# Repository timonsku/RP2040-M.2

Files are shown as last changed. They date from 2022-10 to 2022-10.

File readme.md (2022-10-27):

## RP2040 M.2 USB Card

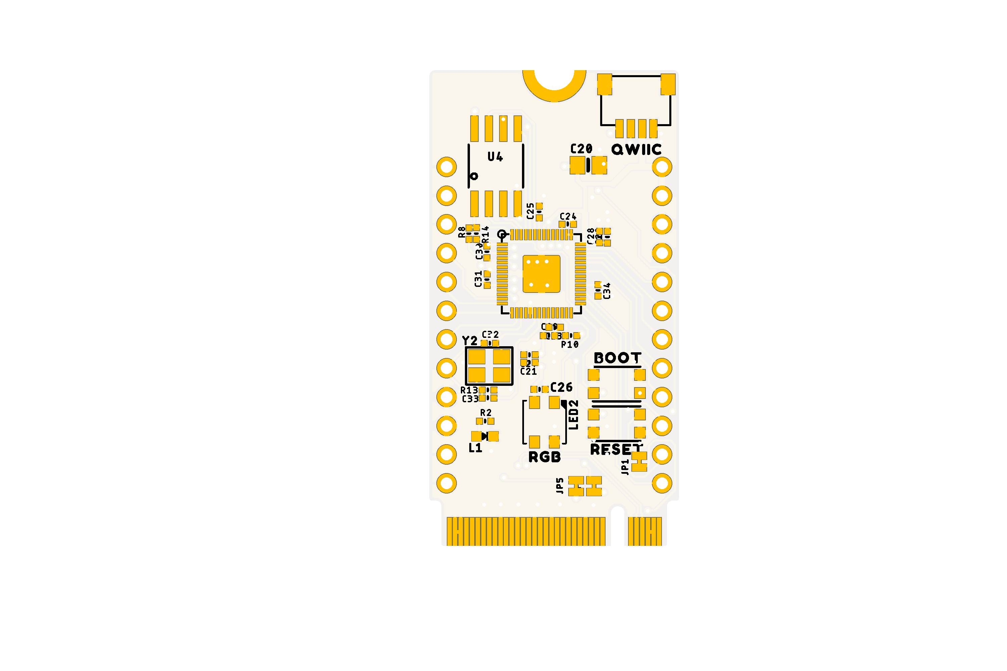
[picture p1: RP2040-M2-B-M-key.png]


### Description
A prototype to demonstrate a M.2 card using the B-Key formfactor using the USB port present on M.2 B-Key slots.
May contain bugs so use with caution.

Twitter thread with more context: https://twitter.com/timonsku/status/1376209933381816324

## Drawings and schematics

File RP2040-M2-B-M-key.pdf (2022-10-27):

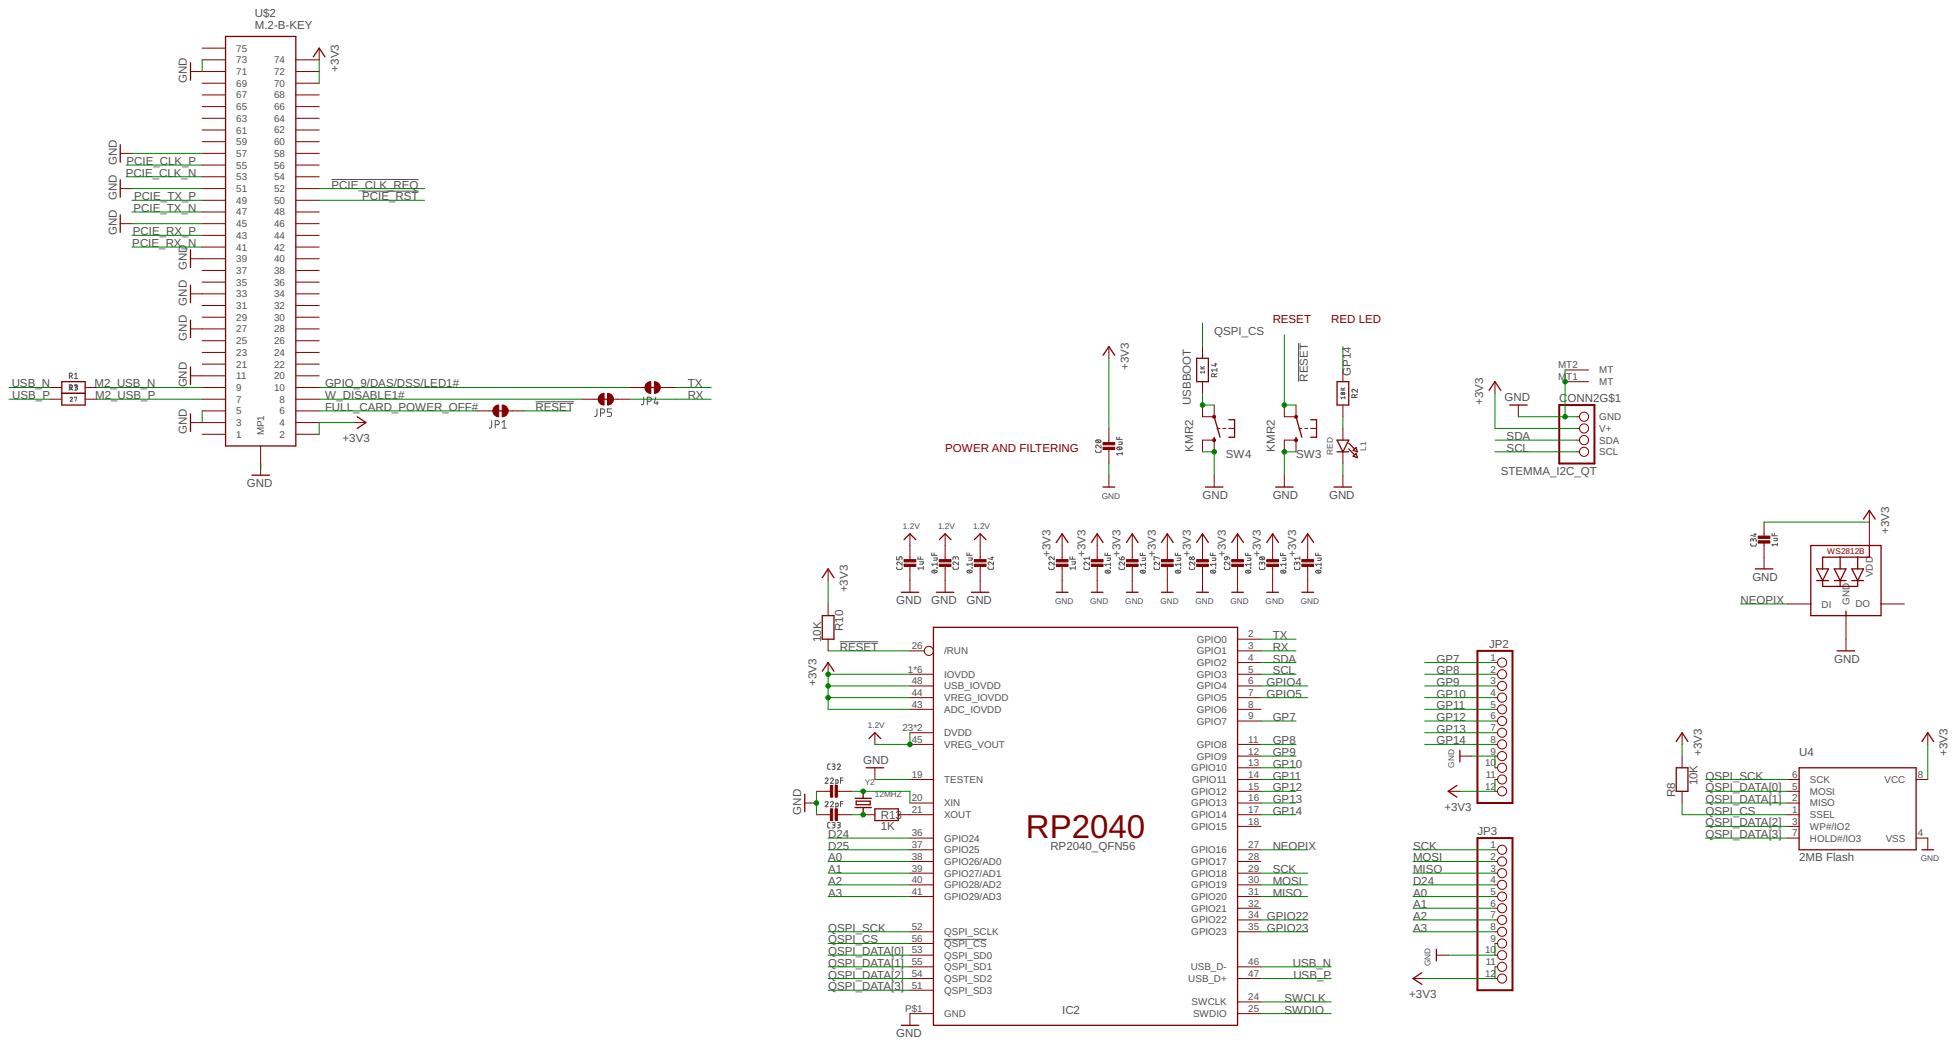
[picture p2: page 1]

RED GND GND KMR2 +3V3 GND GND GND 10K +3V3 +3V3 RP2040_QFN56 10K +3V3 +3V3 GND GND STEMMA_I2C_QT +3V3 GND 1.2V12MHZ 1.2V GND 1.2V GND 1.2V GND +3V3 GND +3V3 GND +3V3 GND +3V3 GND +3V3 GND +3V3 GND +3V3 GND +3V3 GND GND 1K KMR2 GND GND +3V3 M.2-B-KEY GND +3V3 +3V3 GND GND GND GND GND GND GND GND GND +3V3 +3V3 GND GND L1 SW3 VDD DI GND DO SCK 6 MOSI 5 MISO 2 SSEL 1 WP#/IO2 3 HOLD#/IO3 7 VCC 8 VSS 4 U4 2MB Flash R8 GND P$1 ADC_IOVDD 43 GPIO16 27 GPIO17 28 GPIO18 29 GPIO19 30 GPIO22 34 GPIO23 35 SWCLK 24 SWDIO 25 GPIO9 12 GPIO8 11 GPIO15 18 GPIO11 14 GPIO14 17 GPIO10 13 /RUN 26 GPIO6 8 GPIO0 2 GPIO1 3 GPIO2 4 GPIO3 5 GPIO4 6 GPIO5 7 GPIO7 9 DVDD 23*2 IOVDD 1*6 VREG_IOVDD 44 GPIO26/AD0 38 GPIO27/AD1 39 GPIO28/AD2 40 GPIO29/AD3 41 GPIO12 15 GPIO13 16 GPIO20 31 GPIO21 32 GPIO24 36 GPIO25 37 TESTEN 19 XIN 20 XOUT 21 VREG_VOUT 45 USB_D- 46 USB_D+ 47 USB_IOVDD 48 QSPI_SCLK 52 QSPI_CS 56 QSPI_SD0 53 QSPI_SD1 55 QSPI_SD2 54 QSPI_SD3 51 IC2 R10 GND V+SDA SCL CONN2G$1 MT MT1 MT MT2 Y2 R13 SW4 1 2 3 4 5 6 7 8 9 10 11 20 21 22 23 24 25 26 27 28 29 30 31 32 33 34 35 36 37 38 39 40 41 42 43 44 45 46 47 48 49 50 51 52 53 54 55 56 57 58 59 60 61 62 63 64 65 66 67 68 69 70 71 72 73 74 75 MP1 U$2 123456789101112JP2 123456789101112 JP3 MOSI MOSI MISO SCK MISO SCK D24 D24 A3 A3 A2 A2 A1 A1 A0 A0 SCL SCL SDA SDA NEOPIX NEOPIX GP9 GP9 GP8 GP8 RESET RESET RESET QSPI_DATA[0] QSPI_DATA[0] QSPI_DATA[1] QSPI_DATA[1] QSPI_SCK QSPI_SCK QSPI_CS QSPI_CS QSPI_CS QSPI_DATA[3] QSPI_DATA[3] QSPI_DATA[2] QSPI_DATA[2] GP7 GP7 SWCLK SWDIO TX TX RX RX D25 USBBOOT PCIE_CLK_P PCIE_CLK_N PCIE_RX_P PCIE_RX_N PCIE_TX_P PCIE_TX_N PCIE_CLK_REQ PCIE_RST M2_USB_N M2_USB_P W_DISABLE1# FULL_CARD_POWER_OFF# GPIO_9/DAS/DSS/LED1# GPIO22 GPIO23 GPIO4 GPIO5 GP10 GP10 GP11 GP11 GP12 GP12 GP13 GP13 GP14 GP14 GP14 USB_N USB_N USB_P USB_P POWER AND FILTERING RESET RED LED WS2812B RP2040

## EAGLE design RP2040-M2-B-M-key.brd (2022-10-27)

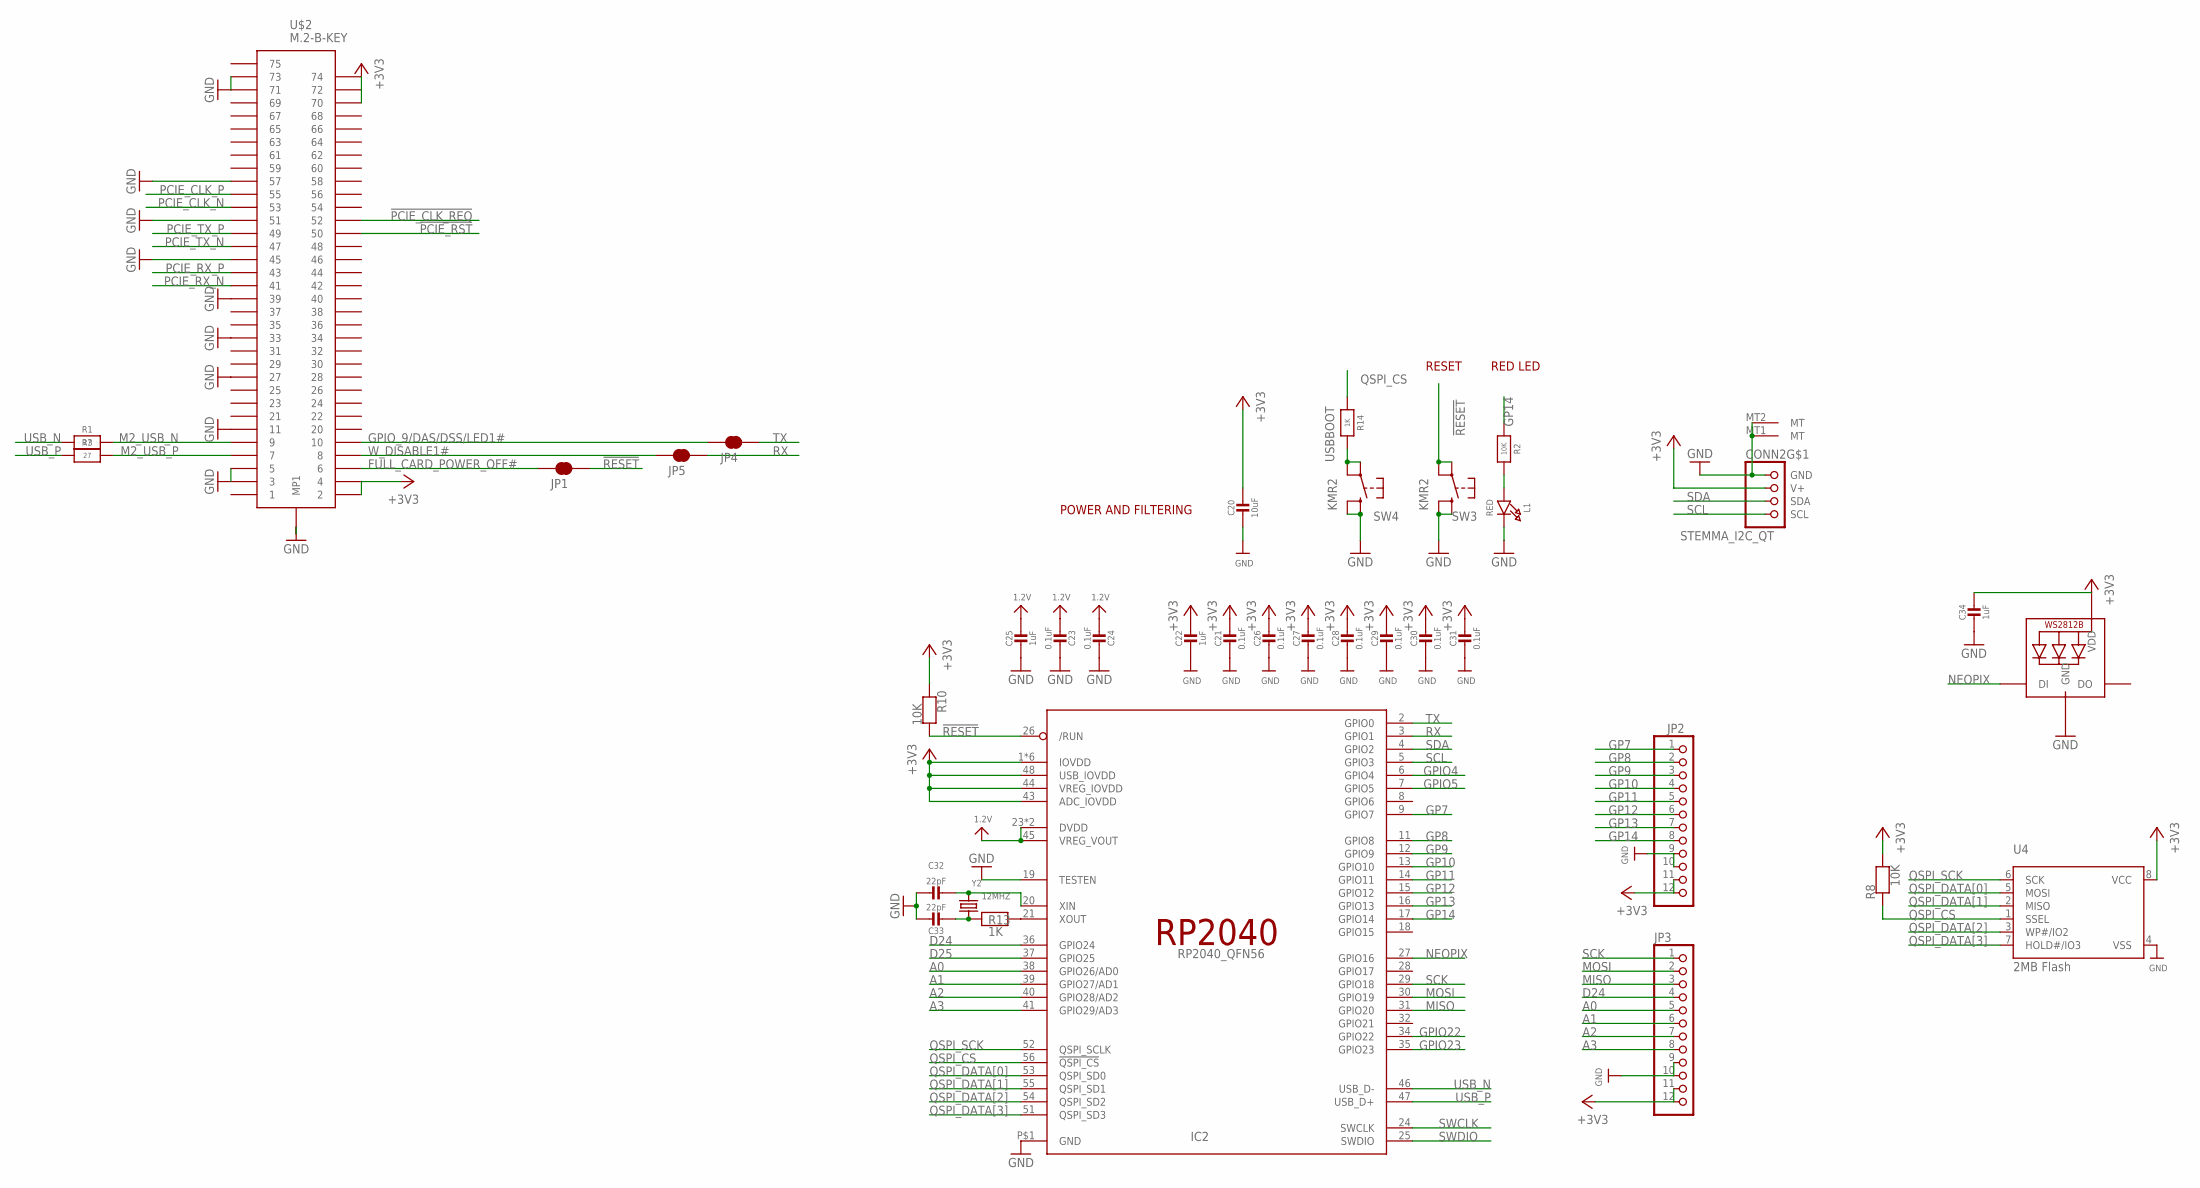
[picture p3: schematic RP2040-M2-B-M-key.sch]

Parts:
C20: 10uF; 0805-NO
C21, C23, C24, C26, C27, C28, C29, C30, C31: 0.1uF; _0402MP
C22, C25, C34: 1uF; _0402MP
C32, C33: 22pF; _0402MP
CONN2: STEMMA_I2C_QT; JST_SH4
IC2: RP2040_QFN56; QFN56_7MM_REDUCEDEPAD
JP1, JP4, JP5: JUMPER-SMT_2_NC_TRACE_NO-SILK; SMT-JUMPER_2_NC_TRACE_NO-SILK
JP2, JP3: HEADER-1X12; 1X12_ROUND
L1: RED; CHIPLED_0603_NOOUTLINE
LED2: WS2812B3535; LED3535
R1, R3: 27; _0402MP
R2, R8, R10: 10K; _0402MP
R13, R14: 1K; _0402MP
SW3, SW4: KMR2; BTN_KMR2_4.6X2.8
U4: 2MB Flash; SOIC8_208MIL
U$2: M.2-B-KEY
Y2: 12MHZ; CRYSTAL_3.2X2.5

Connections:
1.2V: C23.2, C24.2, C25.1, IC2.23 (DVDD), IC2.45 (VREG_VOUT), IC2.50 (DVDD)
!PCIE_CLK_REQ: U$2.P$52 (52)
!PCIE_RST: U$2.P$50 (50)
!RESET: IC2.26 (/RUN), JP1.2, R10.2, SW3.A, SW3.A' (P1)
+3V3: C20.1, C21.1, C22.1, C26.1, C27.1, C28.1, C29.1, C30.1, C31.1, C34.1, CONN2.2 (V+), IC2.1 (IOVDD), IC2.10 (IOVDD), IC2.22 (IOVDD), IC2.33 (IOVDD), IC2.42 (IOVDD), IC2.43 (ADC_IOVDD), IC2.44 (VREG_IOVDD), IC2.48 (USB_IOVDD), IC2.49 (IOVDD), JP2.11, JP2.12, JP3.11, JP3.12, LED2.2 (VDD), R8.2, R10.1, U4.8 (VCC), U$2.P$2 (2), U$2.P$4 (4), U$2.P$70 (70), U$2.P$72 (72), U$2.P$74 (74)
A0: IC2.38 (GPIO26/AD0), JP3.5
A1: IC2.39 (GPIO27/AD1), JP3.6
A2: IC2.40 (GPIO28/AD2), JP3.7
A3: IC2.41 (GPIO29/AD3), JP3.8
D24: IC2.36 (GPIO24), JP3.4
D25: IC2.37 (GPIO25)
FULL_CARD_POWER_OFF#: JP1.1, U$2.P$6 (6)
GND: C20.2, C21.2, C22.2, C23.1, C24.1, C25.2, C26.2, C27.2, C28.2, C29.2, C30.2, C31.2, C32.1, C33.1, C34.2, CONN2.1 (GND), CONN2.MT1 (MT), CONN2.MT2 (MT), IC2.19 (TESTEN), IC2.P$1 (GND), JP2.9, JP2.10, JP3.9, JP3.10, L1.C, LED2.4 (GND), SW3.B (S), SW3.B' (S1), SW4.B (S), SW4.B' (S1), U4.4 (VSS), U$2.MOUNTING-HOLE (MP1), U$2.P$3 (3), U$2.P$5 (5), U$2.P$11 (11), U$2.P$27 (27), U$2.P$33 (33), U$2.P$39 (39), U$2.P$45 (45), U$2.P$51 (51), U$2.P$57 (57), U$2.P$71 (71), U$2.P$73 (73)
GP7: IC2.9 (GPIO7), JP2.1
GP8: IC2.11 (GPIO8), JP2.2
GP9: IC2.12 (GPIO9), JP2.3
GP10: IC2.13 (GPIO10), JP2.4
GP11: IC2.14 (GPIO11), JP2.5
GP12: IC2.15 (GPIO12), JP2.6
GP13: IC2.16 (GPIO13), JP2.7
GP14: IC2.17 (GPIO14), JP2.8, R2.1
GPIO4: IC2.6 (GPIO4)
GPIO5: IC2.7 (GPIO5)
GPIO22: IC2.34 (GPIO22)
GPIO23: IC2.35 (GPIO23)
GPIO_9/DAS/DSS/LED1#: JP4.1, U$2.P$10 (10)
M2_USB_N: R1.2, U$2.P$9 (9)
M2_USB_P: R3.2, U$2.P$7 (7)
MISO: IC2.31 (GPIO20), JP3.3
MOSI: IC2.30 (GPIO19), JP3.2
unnamed: L1.A, R2.2
unnamed: IC2.21 (XOUT), R13.2
unnamed: C32.2, IC2.20 (XIN), Y2.2
unnamed: C33.2, R13.1, Y2.1
NEOPIX: IC2.27 (GPIO16), LED2.1 (DI)
PCIE_CLK_N: U$2.P$53 (53)
PCIE_CLK_P: U$2.P$55 (55)
PCIE_RX_N: U$2.P$41 (41)
PCIE_RX_P: U$2.P$43 (43)
PCIE_TX_N: U$2.P$47 (47)
PCIE_TX_P: U$2.P$49 (49)
QSPI_CS: IC2.56 (!QSPI_CS), R8.1, R14.1, U4.1 (SSEL)
QSPI_DATA[0]: IC2.53 (QSPI_SD0), U4.5 (MOSI)
QSPI_DATA[1]: IC2.55 (QSPI_SD1), U4.2 (MISO)
QSPI_DATA[2]: IC2.54 (QSPI_SD2), U4.3 (WP#/IO2)
QSPI_DATA[3]: IC2.51 (QSPI_SD3), U4.7 (HOLD#/IO3)
QSPI_SCK: IC2.52 (QSPI_SCLK), U4.6 (SCK)
RX: IC2.3 (GPIO1), JP5.2
SCK: IC2.29 (GPIO18), JP3.1
SCL: CONN2.4 (SCL), IC2.5 (GPIO3)
SDA: CONN2.3 (SDA), IC2.4 (GPIO2)
SWCLK: IC2.24 (SWCLK)
SWDIO: IC2.25 (SWDIO)
TX: IC2.2 (GPIO0), JP4.2
USBBOOT: R14.2, SW4.A, SW4.A' (P1)
USB_N: IC2.46 (USB_D-), R1.1
USB_P: IC2.47 (USB_D+), R3.1
W_DISABLE1#: JP5.1, U$2.P$8 (8)

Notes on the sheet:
POWER AND FILTERING
RESET
RED LED

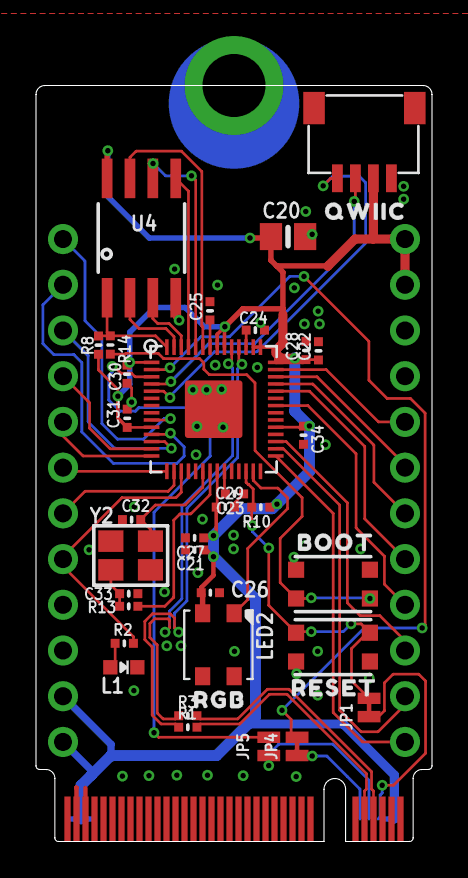
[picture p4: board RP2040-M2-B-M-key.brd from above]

Board: 2 copper layers, 22.0 x 42.0 mm, 41 parts (1 on the bottom side), 43 nets.

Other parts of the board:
U$4: BOOT0
U$5: RESET0
U$6: QWIIC0
U$7: RGB0
U$8: DIODES-DELIGHT-LOGO-10X10-TPLACE

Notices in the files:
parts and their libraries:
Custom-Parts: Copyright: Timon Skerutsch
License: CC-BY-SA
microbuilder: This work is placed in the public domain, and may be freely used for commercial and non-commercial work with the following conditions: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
